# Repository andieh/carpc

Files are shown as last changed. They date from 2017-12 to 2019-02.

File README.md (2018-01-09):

# carpc
Digitalization of an old VW T3 Bulli

My old VW bulli needs some fancy power control. Mainly control of lights inside the van, disconnecting 5V power supply, theft control and so on. As an Add-on, my van has a "new" engine. The subaru EJ22 is also a boxer engine, but with way more power. And as this engine has some sort of diagnostics (pre-ODB2) included, it would be nice to visualize those informations as well.

so this project consists mainly of 3 parts:
- An Arduino (only for the easy for programming, code is plain C) (work in progress)
- A Raspberry Pi with Touchscreen and CarPC Kodi Interface (work in progress)
- ESP8266 IoT Chip for Wireless control of the functionality (t.b.d)

## Atmega328
This is the main part of the projects. Located in the back, this device will be always on. controlled by a 3x2 button interface, it enables the LED stripes in the back, starts the heater, turn on or off the 5V supply and so on. A horn is connected for alarm purposes. It checks the door state, or if the car was locked or not. 

## Raspberry Pi
Mainly for music, but also displays diagnostics from the engine, shows a navigation plugin or shows a rear cam. i currently implemented 3 plugins:
- GPIO service (enable rear cam, power enable, etc).
- Rear cam display: shows an overlay for the connected camera (usb analog s-video grabber and v4l2 / mplayer)
- Display of the EJ22 data (finished, but connection missing)

### Used Components
- Raspberry PI v.3
- Optocoupler ltv847 for detecting 12V / 5V voltages
- Servo for open and closing the display lid 
- Switch for detecting the state of the display lid
- electromagnet for holding the display lid
- Levelshifter TE291 for USART communication between Arduino / Raspbi
- IRLB8721 N-Channel Mosfets for LED stripes (controlled by the arduino)
- IRF9Z P-Channel (and BS107 Transistor) switch the 12V rail for the rear cam
- DHT 22 / AM2302 Temperature sensor 

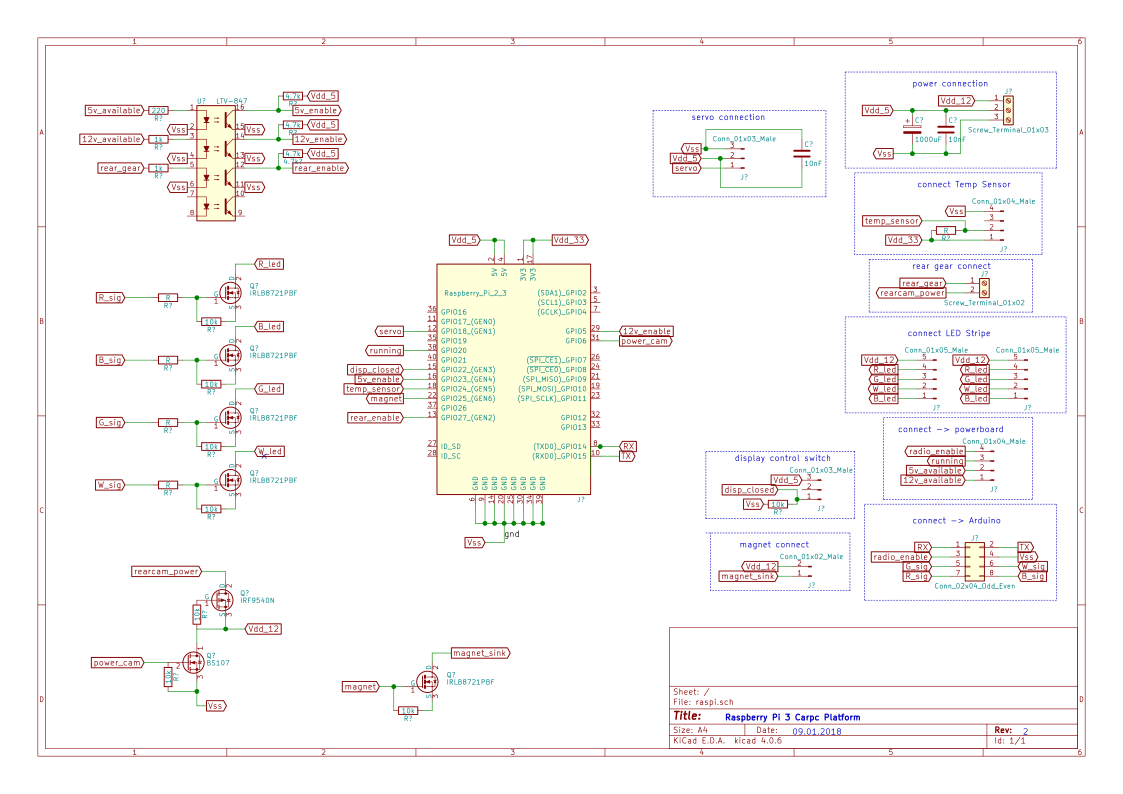
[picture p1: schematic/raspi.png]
rasp_schem


### Power supply
First try was with a 18650 Battery pack, but the Raspi, including 7'' touch
screen and GPS / Stick / S-Video consumes a lot of power (about 2-3 Amps max), 
i decided to build some analog voodoo, since there is a very big battery
already included in my (every) car. There are several ways to enable the 12V
supply: 
- button on the Arduino
- the arduino itself (with a GPIO, so power is guaranteed as long it is running)
- over the ignition
If all requests were removed, a big cap (220u) is still providing power for
some time (>10s) for the N-PMOS gate to ensure the Raspi has enough time to
shutdown. There are 3 MP1584 Buck Converter (step down) modules, which power the 
raspberry itself, one for the display and one for the USB hub. 

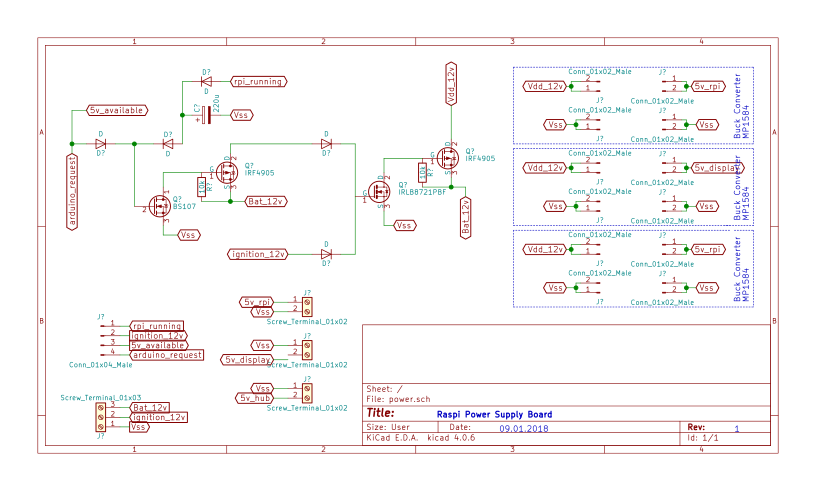
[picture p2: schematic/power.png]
power_schem


## ESP8266
Nice small thing to play with. Is directly connected to the EJ22 engine and sends data via broadcast. but currently not work in progress. to be implemented later.

Schematics (created with kicad) will be updated on time, details and more to come soon.

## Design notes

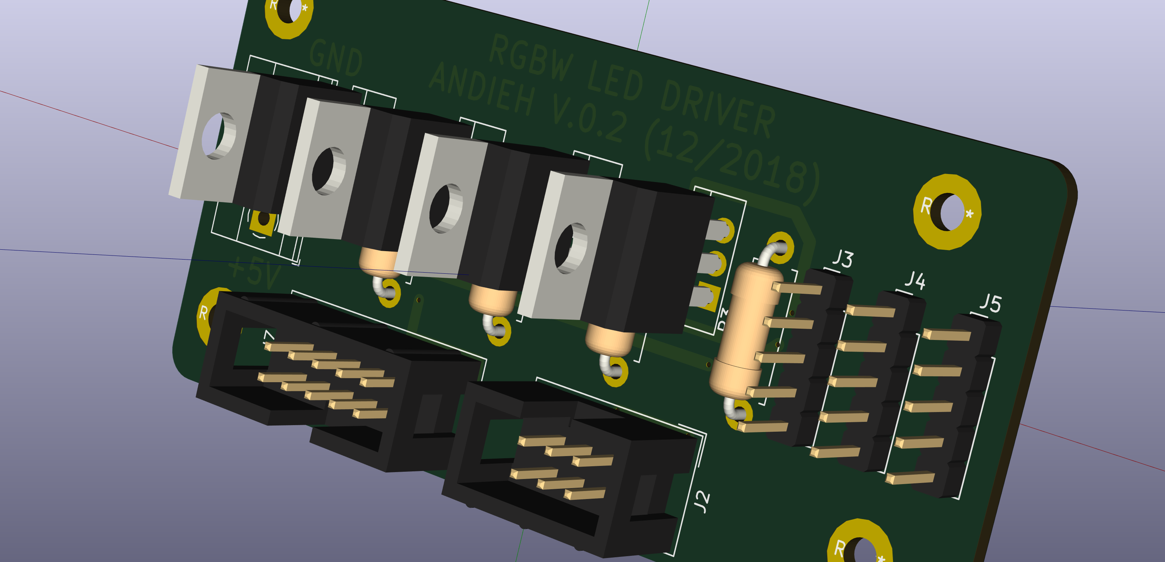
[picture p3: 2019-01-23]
schematic/led-control/led_control.png

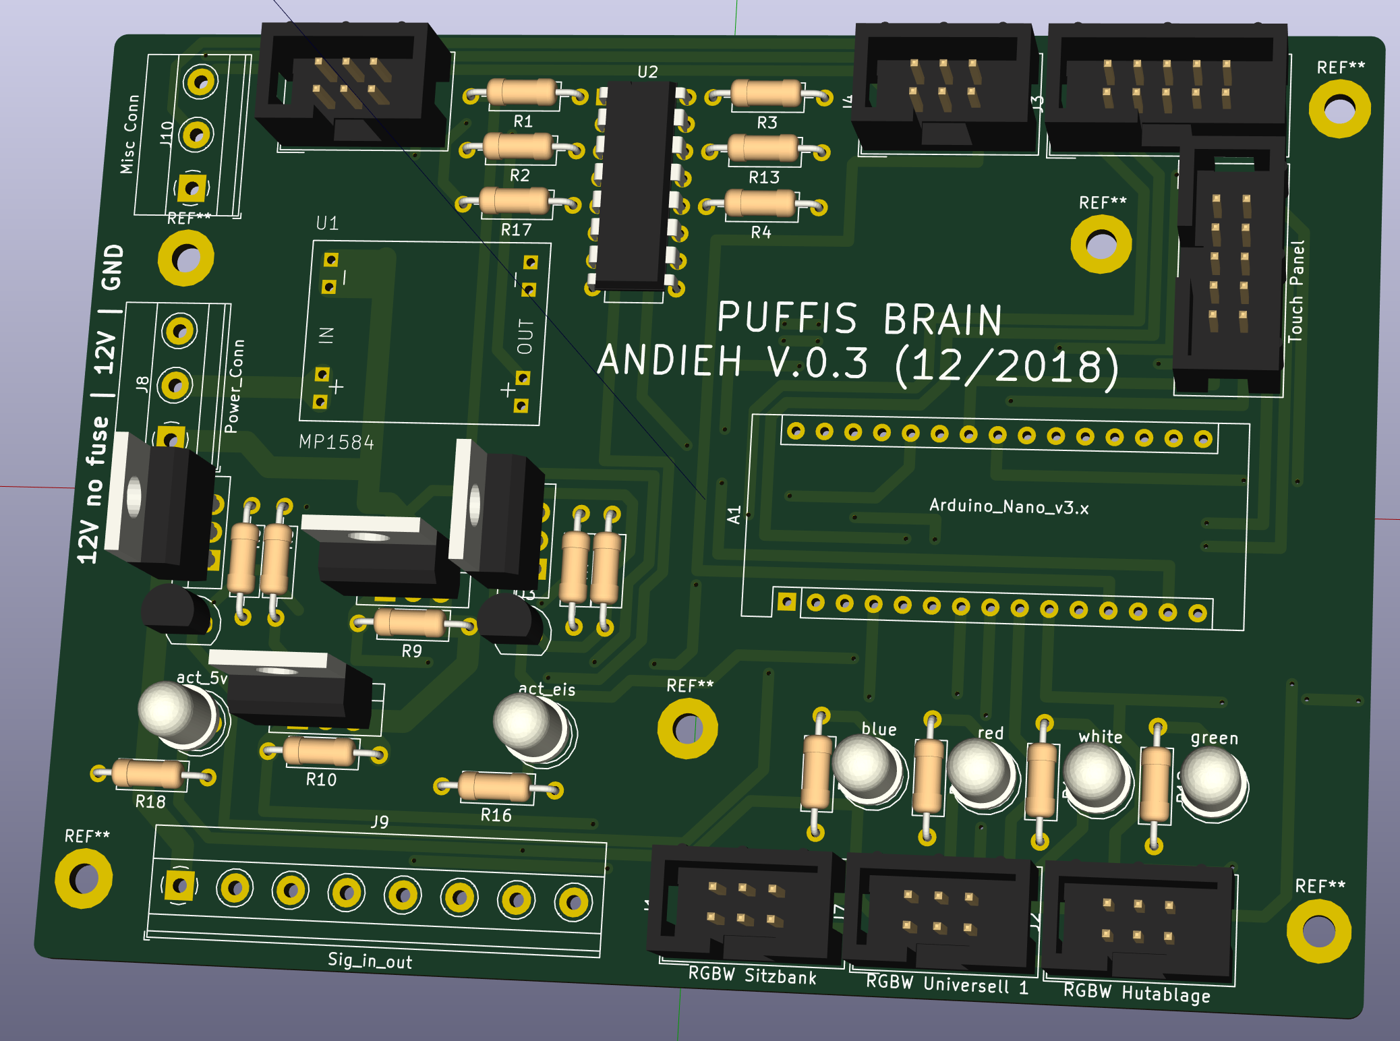
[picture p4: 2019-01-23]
schematic/car-control/car-control.png

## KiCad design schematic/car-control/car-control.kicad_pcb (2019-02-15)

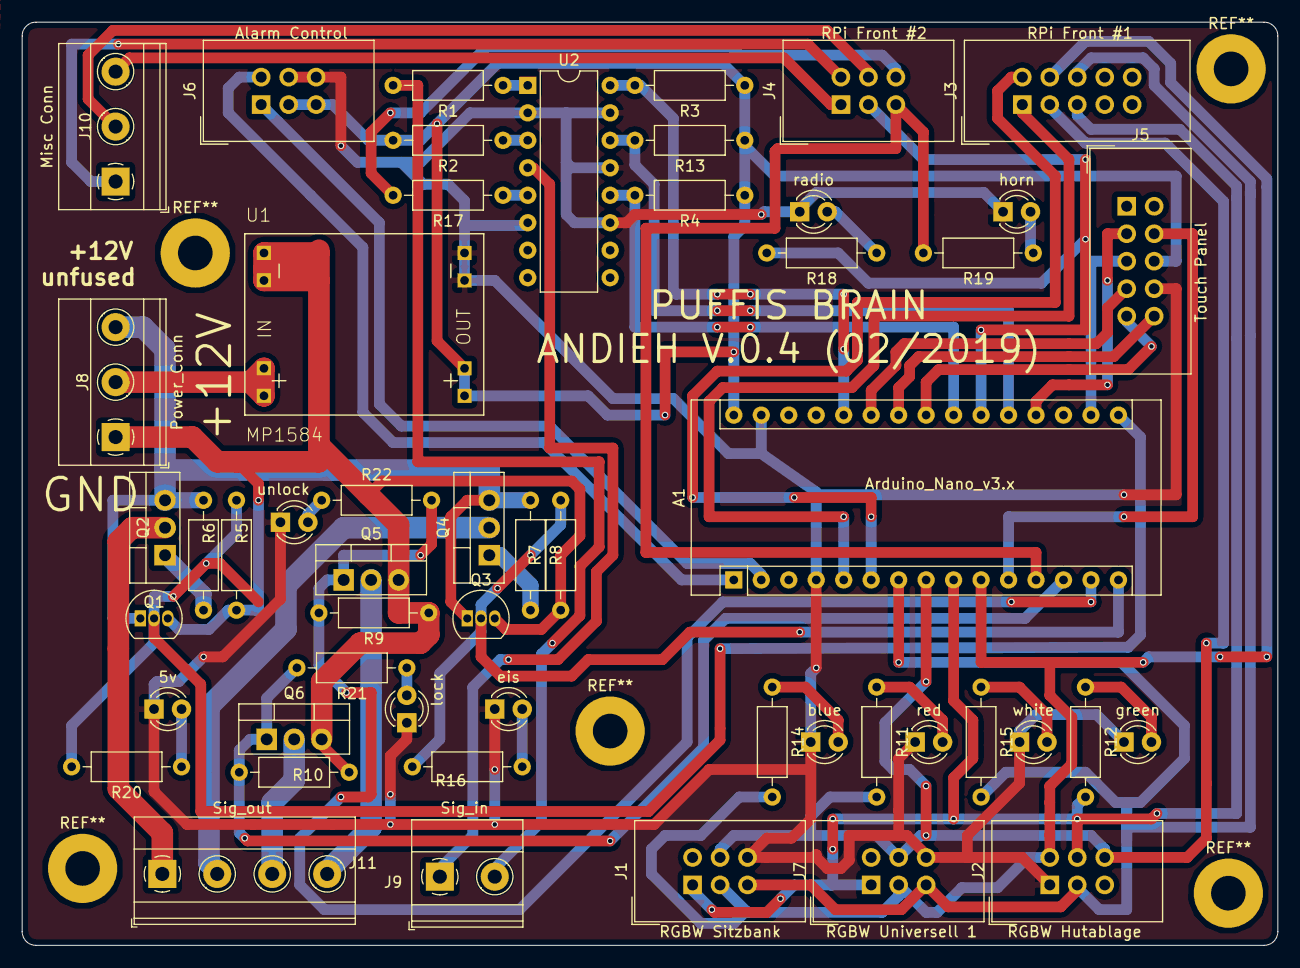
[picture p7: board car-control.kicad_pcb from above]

Board: 2 copper layers, 116.1 x 85.3 mm, 52 parts (0 on the bottom side), 53 nets.

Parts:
5v: act_5v; LED_D3.0mm_Clear
A1: Arduino_Nano_v3.x; Arduino_Nano
J1: RGBW Sitzbank; IDC-Header_2x03_P2.54mm_Vertical
J2: RGBW Hutablage; IDC-Header_2x03_P2.54mm_Vertical
J3: RPi Front #1; IDC-Header_2x05_P2.54mm_Vertical
J4: RPi Front #2; IDC-Header_2x03_P2.54mm_Vertical
J5: Touch Panel; IDC-Header_2x05_P2.54mm_Vertical
J6: Alarm Control; IDC-Header_2x03_P2.54mm_Vertical
J7: RGBW Universell 1; IDC-Header_2x03_P2.54mm_Vertical
J8: Power_Conn; TerminalBlock_Phoenix_MKDS-1,5-3-5.08_1x03_P5.08mm_Horizont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
J9: Sig_in; TerminalBlock_Phoenix_MKDS-1,5-2-5.08_1x02_P5.08mm_Horizont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
J10: Misc Conn; TerminalBlock_Phoenix_MKDS-1,5-3-5.08_1x03_P5.08mm_Horizont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
J11: Sig_out; TerminalBlock_Phoenix_MKDS-1,5-4-5.08_1x04_P5.08mm_Horizont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
Q1, Q3: BS107; TO-92_Inline
Q2, Q4: IRF9540N; TO-220-3_Vertical
Q5, Q6: IRLB8721PBF; TO-220-3_Vertical
R1, R2, R11, R12, R15, R16, R18, R19, R20, R21, R22: 220; R_Axial_DIN0207_L6.3mm_D2.5mm_P10.16mm_Horizontal
R3, R4, R13: 4.7k; R_Axial_DIN0207_L6.3mm_D2.5mm_P10.16mm_Horizontal
R5, R6, R7, R8, R9, R10: 10k; R_Axial_DIN0207_L6.3mm_D2.5mm_P10.16mm_Horizontal
R14: 120; R_Axial_DIN0207_L6.3mm_D2.5mm_P10.16mm_Horizontal
R17: 680; R_Axial_DIN0207_L6.3mm_D2.5mm_P10.16mm_Horizontal
U1: MP1584; SG053-SZ
U2: LTV-847; DIP-16_W7.62mm
blue: blue; LED_D3.0mm_Clear
eis: act_eis; LED_D3.0mm_Clear
green: green; LED_D3.0mm_Clear
horn: horn; LED_D3.0mm_Clear
lock: lock; LED_D3.0mm_Clear
radio: radio; LED_D3.0mm_Clear
red: red; LED_D3.0mm_Clear
unlock: unlock; LED_D3.0mm_Clear
white: white; LED_D3.0mm_Clear

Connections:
/220_avail: J9.2, R1.2
/220_led: A1.19, J5.3
/GND: 5v.1, A1.4, A1.29, J1.6, J2.1, J5.8, J6.4, J6.6, J7.6, U1.5, U1.6, U2.2, U2.6, U2.11, U2.13, U2.15, blue.1, eis.1, green.1, horn.1, lock.1, radio.1, red.1, unlock.1, white.1
/RX: A1.2, J6.1
/SCL: A1.23, J5.9
/SDA: A1.24, J5.10
/TX: A1.1, J6.2
/VDD: A1.30, J5.6, J6.3, J6.5, R2.2, R3.1, R4.1, R13.1, U1.7, U1.8
/analog_light: A1.25, J5.7
/cam_1_g: J4.1, J10.3
/cam_2_r: J4.2, J10.1
/cam_3_s: J4.4, J10.2
/door_gnd: J9.1, U2.4
/inp_12v: J8.2, U1.3, U1.4
/inp_12v_unfused: J8.3, Q1.1, Q2.3, Q3.1, Q4.3, R6.1, R8.1
/inp_gnd: J8.1, Q1.3, Q3.3, Q5.3, Q6.3, R5.1, R7.1, R9.1, R10.1, U1.1, U1.2
/lock_car: J11.3, Q6.2
/power_5v: J11.1, Q2.2
/power_eis: J11.2, Q4.2
/pwm_touch: A1.11, J5.4
/sig_5v: A1.16, Q1.2, R5.2, R20.2
/sig_220v: A1.26, R3.2, U2.16
/sig_b: A1.10, J1.3, J2.2, J3.4, J7.3, R14.2
/sig_door: A1.20, R13.2, U2.14
/sig_eis: A1.15, Q3.2, R7.2, R16.2
/sig_g: A1.9, J1.1, J2.4, J3.5, J7.1, R12.2
/sig_horn: A1.12, J4.5, R19.2
/sig_lock: A1.13, Q6.1, R10.2, R21.2
/sig_lock_inp: J4.6, R17.2
/sig_locked: A1.22, R4.2, U2.12
/sig_r: A1.8, J1.4, J2.6, J3.3, J7.4, R11.2
/sig_radio: A1.21, J4.3, R18.2
/sig_unlock: A1.14, Q5.1, R9.2, R22.2
/sig_w: A1.7, J1.5, J2.3, J3.6, J7.5, R15.2
/soft_RX: A1.5, J3.1
/soft_TX: A1.6, J3.2
/unlock_car: J11.4, Q5.2
/v33: A1.17, J5.5
unnamed: R11.1, red.2
unnamed: R12.1, green.2
unnamed: R14.1, blue.2
unnamed: R15.1, white.2
unnamed: R16.1, eis.2
unnamed: R19.1, horn.2
unnamed: R18.1, radio.2
unnamed: 5v.2, R20.1
unnamed: R21.1, lock.2
unnamed: R22.1, unlock.2
unnamed: Q2.1, R6.2
unnamed: Q4.1, R8.2
unnamed: R1.1, U2.1
unnamed: R2.1, U2.3
unnamed: R17.1, U2.5

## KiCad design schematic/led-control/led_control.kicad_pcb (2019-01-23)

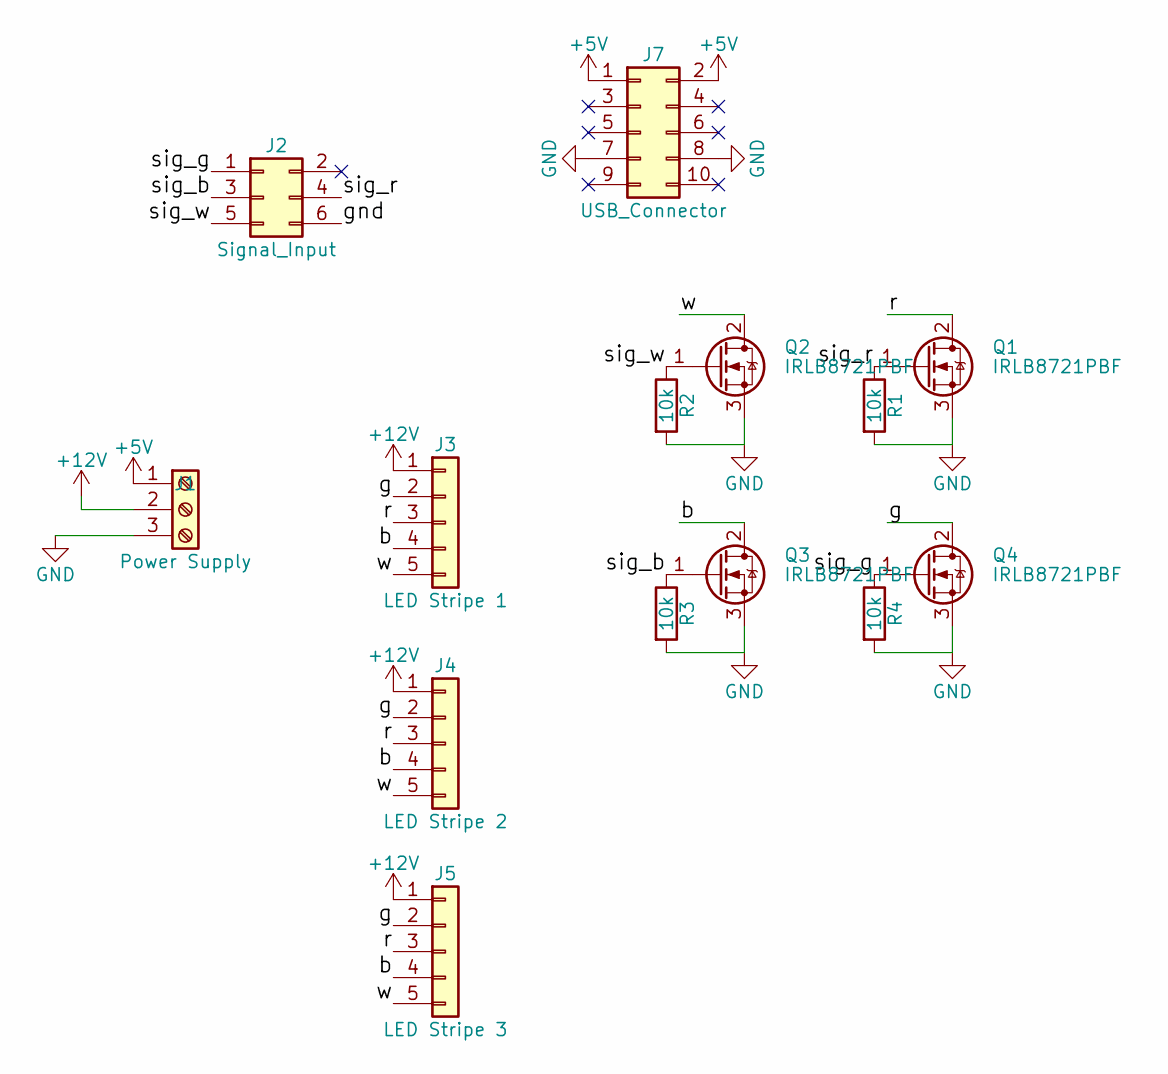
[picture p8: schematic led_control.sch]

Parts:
J1: Power Supply; TerminalBlock_Phoenix_MKDS-1,5-3-5.08_1x03_P5.08mm_Horizont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
J2: Signal_Input; IDC-Header_2x03_P2.54mm_Vertical
J3: LED Stripe 1; PinHeader_1x05_P2.54mm_Vertical
J4: LED Stripe 2; PinHeader_1x05_P2.54mm_Vertical
J5: LED Stripe 3; PinHeader_1x05_P2.54mm_Vertical
J7: USB_Connector; IDC-Header_2x05_P2.54mm_Vertical
Q1, Q2, Q3, Q4: IRLB8721PBF; TO-220-3_Vertical
R1, R2, R3, R4: 10k; R_Axial_DIN0411_L9.9mm_D3.6mm_P12.70mm_Horizontal

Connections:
+5V: J1.1, J7.1, J7.2
+12V: J1.2, J3.1, J4.1, J5.1
/b: J3.4, J4.4, J5.4, Q3.2 (D)
/g: J3.2, J4.2, J5.2, Q4.2 (D)
/r: J3.3, J4.3, J5.3, Q1.2 (D)
/sig_b: J2.3, Q3.1 (G), R3.1
/sig_g: J2.1, Q4.1 (G), R4.1
/sig_r: J2.4, Q1.1 (G), R1.1
/sig_w: J2.5, Q2.1 (G), R2.1
/w: J3.5, J4.5, J5.5, Q2.2 (D)
GND: J1.3, J2.6, J7.7, J7.8, Q1.3 (S), Q2.3 (S), Q3.3 (S), Q4.3 (S), R1.2, R2.2, R3.2, R4.2

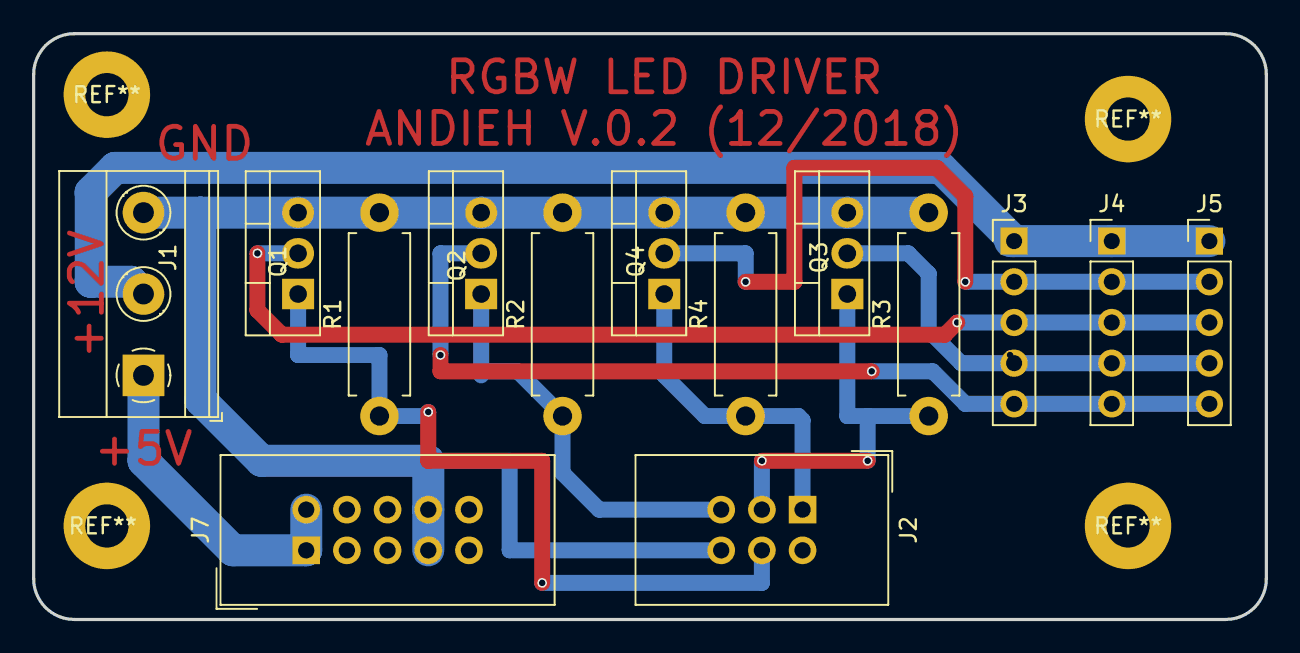
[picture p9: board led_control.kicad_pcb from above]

Board: 2 copper layers, 77.0 x 36.6 mm, 14 parts (0 on the bottom side), 11 nets.

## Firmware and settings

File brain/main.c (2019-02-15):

/**************************
 * PUFFIS BRAIN, Car-Control v.0.2
 *
 * PORTB
 * PB0  D8   >  touch_pwm   Dims the LEDs on the Touch board 
 * PB1  D9   >  sig_horn    For alarm purpurses, enable horn. 
 *                          \Todo: own board for power control?
 * PB2  D10  >  sig_lock    Locks the car using a N-Transistor
 * PB3  D11  >  NEW: sig_unlock
 *                   replaced sig_220v    check if 220V are available. 5V is read
 *                          by the optocoppler
 * PB4  D12  >  sig_eis     Enables the 12V P-Transistor output for 
 *                          the EisEx.
 * PB5  D13  >  sig_5v      Enables 12V for the 5V rail.
 *
 * PORTC
 * PC0  A0   >  NEW: 220_led
 *                   replaced analog_light  measure voltage for dimming touch LEDs
 * PC1  A1   <  sig_door      doors were opened (ground enabled)
 * PC2  A2   >  sig_radio     enabled radio in the front
 * PC3  A3   <  sig_locked    high if car is locked
 * PC4  A4   >  NEW: SCL      
 *                   replaced 220_led       indicates 220V are available 
 * PC5  A5   >  NEW: SCA      
 *                   replaced SCL i2c for touch panel
 * PC6  A6   <  NEW: analog_light   
 *                   replaced SDA i2c for touch panel
 * PC7  A7   <  NEW: sig_220v
 *                   replaced sig_unlock    Unlocks the car using a N-Transistor
 *
 * PORTD
 * PD0  RX   <  RX          Receive Data from the Arduino
 * PD1  TX   >  TX          Trasmit Data to the Alarm Arduino
 * PD2  D2   <  soft_RX     Receive Data from the RPI 
 *                          \Todo: implement this!
 * PD3  D3   >  soft TX     Transmit Data to the RPI 
 *                          \Todo: implement this!
 * PD4  D4   >  sig_w       LED Stripe, white LED
 * PD5  D5   >  sig_r       LED Stripe, red LED
 * PD6  D6   >  sig_g       LED Stripe, green LED
 * PD7  D7   >  sig_b       LED Stripe, blue LED
 *
 */

#include <avr/io.h>
#include <avr/pgmspace.h>
#include <avr/interrupt.h>
#include "types.h"
#include "defs.h"
#include <util/delay.h>
#include "i2c.h"
#include "mpr121.h"
#include "stdbool.h"
#define FOSC 8000000
#define MPR121_R 0xB5	// ADD pin is grounded
#define MPR121_W 0xB4	// So address is 0x5A

#define sbi(var, mask)   ((var) |= (uint8_t)(1 << mask))
#define cbi(var, mask)   ((var) &= (uint8_t)~(1 << mask))

#define F_PWM 100                       // PWM-Frequenz in Hz
#define PWM_STEPS 256                   // PWM-Schritte pro Zyklus(1..256)
#define PWM_DDR DDRD                    // Datenrichtungsregister für PWM

// ab hier nichts ändern, wird alles berechnet
#define T_PWM (F_CPU/(F_PWM*PWM_STEPS)) // Systemtakte pro PWM-Takt
#if (T_PWM<(93+5))
    #error T_PWM zu klein, F_CPU muss vergrössert werden oder F_PWM oder PWM_STEPS verkleinert werden
#endif

#define LED_COLOR_WHITE 0
#define LED_COLOR_BLUE 1
#define LED_COLOR_RED 2
#define LED_COLOR_GREEN 3
#define LED_COLOR_TOUCH 4

#define LED_PORT_TOUCH  PORTB
#define LED_PIN_TOUCH   PORTB0
#define LED_PORT_WHITE  PORTD
#define LED_PIN_WHITE   PORTD4
#define LED_PORT_RED    PORTD
#define LED_PIN_RED     PORTD5
#define LED_PORT_GREEN  PORTD
#define LED_PIN_GREEN   PORTD6
#define LED_PORT_BLUE   PORTD
#define LED_PIN_BLUE    PORTD7

#define IN_PORT_DOOR    PORTC
#define IN_PIN_DOOR     PC1
#define IN_PORT_LOCKED  PORTC 
#define IN_PIN_LOCKED   PC3
#define MAX_LOCK_CNT    100

#define IN_LIGHT_SENSE 6 // PC6
#define IN_220_SENSE 7 // PC7
#define LIGHT_THRESH	512

#define OUT_RADIO_PORT   PORTC
#define OUT_RADIO_PIN    PORTC2
#define OUT_EIS_PORT     PORTB
#define OUT_EIS_PIN      PORTB4
#define OUT_5V_PORT      PORTB
#define OUT_5V_PIN       PORTB5
#define OUT_220_PORT     PORTC 
#define OUT_220_PIN      PORTC0
#define OUT_LOCK_PORT    PORTB 
#define OUT_LOCK_PIN     PORTB2
#define OUT_UNLOCK_PORT  PORTB 
#define OUT_UNLOCK_PIN   PORTB3

// includes

#include <stdint.h>
#include <string.h>
#include <avr/io.h>
#include <avr/interrupt.h>
#include "uart.h"
#define UART_BAUD_RATE 9600
#define BAUDRATE 9600
#define BAUD_PRESCALLER (((F_CPU / (BAUDRATE * 16UL))) - 1)

///============Function Prototypes=========/////////////////
char mpr121Read(unsigned char address);
void mpr121Write(unsigned char address, unsigned char data);
void mpr121QuickConfig(void);
void mpr121ViewRegisters(void);
int checkInterrupt(void);
uint8_t set_new_led_color();
void set_output(volatile uint8_t *port, uint8_t pin, bool value);
ISR (TIMER2_COMPA_vect);
void USART_init(void);
unsigned char USART_receive(void);
void USART_send( unsigned char data);
void USART_putstring(char* StringPtr);
uint16_t adc_read(uint8_t adcx);

volatile uint8_t led_color[5];                    // Einstellungen für die einzelnen PWM-Kanäle
int old_led_value = 0;

int TOUCH_RADIO  = 1 << 2;
int TOUCH_EIS    = 1 << 3;
int TOUCH_LIGHT  = 1 << 4;
int TOUCH_5V     = 1 << 5;
int TOUCH_MISC   = 1 << 6;
int TOUCH_LOCK   = 1 << 7;

int LED_EIS    = 1 << 2;
int LED_LOCK   = 1 << 3;
int LED_LIGHT  = 1 << 4;
int LED_5V     = 1 << 5;
int LED_MISC   = 1 << 6;
int LED_RADIO  = 1 << 7;

bool touched_radio = false;
bool touched_eis = false;
bool touched_light = false;
bool touched_5v = false;
bool touched_misc = false;
bool touched_lock = false;

int main(void)
{
  /* Enable the ADC */
  ADCSRA |= ((1<<ADPS2)|(1<<ADPS1)|(1<<ADPS0));    //16Mhz/128 = 125Khz the ADC reference clock
  ADMUX  |= (1<<REFS0);                //Voltage reference from Avcc (5v)
  ADCSRA |= (1<<ADEN);                //Turn on ADC
  ADCSRA |= (1<<ADSC);
  
  unsigned int c;
  uart_init( UART_BAUD_SELECT(UART_BAUD_RATE,F_CPU) );
  uart_putc('\r');

  /* SOFTPWM STUFF*/
  OCR2A = 62;
  TCCR2A |= (1 << WGM21);
  // Set to CTC Mode
  TIMSK2 |= (1 << OCIE2A);
  //Set interrupt on compare match
  TCCR2B |= (1 << CS21);
  // set prescaler to 64 and starts PWM
  sei();
  // enable interrupts
	
  char touchstatus;
	ioinit();
	i2cInit();
	_delay_ms(100);
	checkInterrupt();
	
  mpr121QuickConfig();
	
	// Setup the GPIO pins to drive LEDs
	mpr121Write(GPIO_EN, 0xFF);	// 0x77 is GPIO enable
	mpr121Write(GPIO_DIR, 0xFF);	// 0x76 is GPIO Dir
	mpr121Write(GPIO_CTRL0, 0xFF);	// Set to LED driver
	mpr121Write(GPIO_CTRL1, 0xFF);	// GPIO Control 1
	mpr121Write(GPIO_CLEAR, 0xFF);	// GPIO Data Clear
	
	/*// Blink LEDs to begin
	for (int i = 0; i < 5; i++)
	{
		mpr121Write(GPIO_SET, 0xFF);
		_delay_ms(50);
		mpr121Write(GPIO_CLEAR, 0xFF);
		_delay_ms(50);
	}*/

  int delay=50;
  int state = 0x00;
  int old_new_state = state;
  
  mpr121Write(GPIO_CLEAR, 0xFF);	// Clear all LEDs
  int cnt = 0;
  int lock_led_cnt = 0;
  int touch_cnt = 0;
  int step = 0;
  uint8_t white_fade = 0;


  bool red_on = false;
  // alarm state
  enum alarm_fsm {
    ALARM_OFF = 0, // alarm is turned off 
    ALARM_WAIT,    // wait until alarm is turned on 
    ALARM_FOCUS,   // alarm is wait until released
    ALARM_DELAY,   // wait to shutdown alarm 
    ALARM          // alarm is triggered
  };
  enum alarm_fsm alarm = ALARM_OFF;  // current fsm 
  bool alarm_state = false; // alarm is active, flash lights
  int alarm_cnt = 0; // cnt for alarm
  bool alarm_triggered = false; // alarm over UART was triggered!
  bool alarm_requested = false; // alarm was requested over UART

  bool door_open = false;
  bool sig_220_out = false;
  bool sig_220_in = false;
  bool sig_in_locked = false;
  const int wait_delay= 100;

  
  /*unsigned char c = 0;*/
  bool uart_com = false;
  bool arg = false;
  uint8_t bus_argc = 0;
  int uart_command = 0;
  int uart_arg = 0;

  bool sig_5v = false;
  bool sig_eis = false;
  bool sig_radio = false;

  // lock stuff 
  int lock_cnt = 1;
  int lock_action = 0; // do nothing

  /* enable pull ups */
  IN_PORT_DOOR &= ~( 1 << IN_PIN_DOOR );
  IN_PORT_LOCKED &= ~( 1 << IN_PIN_LOCKED );

  //DDRD = DDRD | 0b11111000; //PORTD (RX on PD0), IRQ on PD2
	while(1)
	{

    ++cnt;

    if (cnt%500==0) {
      set_new_led_color();
    }

    // check if any of the doors are open
    if (!bit_is_set(PINC, IN_PIN_DOOR)) {
      door_open = true;
    } else {
      door_open = false;
    }

    // check if any of the doors are open
    if (!bit_is_set(PINC, IN_PIN_LOCKED)) {
      sig_in_locked = true;
    } else {
      sig_in_locked = false;
    }

    // check if 220V are available
    uint16_t analog_val_220 = adc_read(IN_220_SENSE);
    if (analog_val_220 < 200) {
      sig_220_in = true;
    } else {
      sig_220_in = false;
    }

    // read cap touch via i2c
		touchstatus = mpr121Read(0x00);	// Read touch status
		touchstatus = touchstatus << 2;	// Shift two bits over
    if (touch_cnt > 0)
      --touch_cnt;
    
    ++step;
    ++alarm_cnt;
    ++lock_cnt;
    
    if (step > 100000) 
      step = 0;
    
    bool touch_change = false;
    if (touch_cnt == 0) {
      for (int i = 2; i < 8; ++i) {
        if (touchstatus & (1<<i)) {
          touch_cnt = wait_delay;
          touch_change = true;
          if (state & (1<<i))
            state &= ~(1<<i);
          else 
            state |= (1<<i);
        }
      }
    }
    
    if (touch_change) {
      //enables light
      if (state & TOUCH_LIGHT) touched_light = true;
      else touched_light = false;
      if (state & TOUCH_EIS) touched_eis = true;
      else touched_eis = false;
      if (state & TOUCH_5V) touched_5v = true;
      else touched_5v = false;
      if (state & TOUCH_MISC) touched_misc = true;
      else touched_misc = false;
      if (state & TOUCH_LOCK) touched_lock = true;
      else touched_lock = false;
      if (state & TOUCH_RADIO) touched_radio = true;
      else touched_radio = false;
    }
 
    if (touched_5v) {
      sig_5v = true;
    } else {
      sig_5v = false;
    }

    if (touched_eis) {
      sig_eis = true;
    } else {
      sig_eis = false;
    }

    if (touched_radio) {
      sig_radio = true;
    } else {
      sig_radio = false;
    }

    if (touched_lock) {
      // we want to lock or unlock the car. 
      // this is based on the state of the car.
      if (sig_in_locked) // car is locked, so we want to unlock it
        lock_action = 1;
      else 
        lock_action = 2;
      lock_cnt = 0;
      state &= ~(TOUCH_LOCK);
      touched_lock = false;
    }

    sig_220_out = sig_220_in;

    c = uart_getc();
    if (!(c&UART_NO_DATA)) {
      //uart_putc( (unsigned char)c );
      if (c == 60) { // start communication with '<'
        uart_com = true;
        arg = false;
        uart_command = 0;
        uart_arg = 0;
  
      } else if (!uart_com) {
        // foo
      
      } else if (c == 62) { // stop communication with '>'
        uart_com = false;
        // run my commands!
        if (uart_command == 48) { // 0
          if (uart_arg == 48) { // off 
            alarm_requested = false; 
            alarm = ALARM_OFF;
            state &= ~(1<<3);
            red_on = false;
          } else if (uart_arg == 49) { // on     
            alarm_requested = true;
            alarm_cnt = 0;
          }
        
        } else if (uart_command == 49) { // 0
          if (uart_arg == 49) { // alarm triggered
            alarm_triggered = true;
          } else if (uart_arg == 48) {
            alarm_triggered = false;
          }
        }

      } else {
        if (!arg) {
          uart_command = c;
          arg = true;
        } else {
          uart_arg = c;
        }
      }

    }



    if (alarm != ALARM) {
      if (door_open || touched_light) {
        if (white_fade < 128) {
          ++white_fade;
          _delay_ms(5);
        }
        led_color[LED_COLOR_WHITE] = white_fade;
      } else if (white_fade > 0) {
        --white_fade;
        _delay_ms(5);
        led_color[LED_COLOR_WHITE] = white_fade;
      } else {
        white_fade = 0;
        led_color[LED_COLOR_WHITE] = 0;
      }
    }
  
    // request alarm over UART
    if (alarm_requested) {
      red_on = true;
    }

    if (alarm == ALARM_OFF) {
      alarm_triggered = false;
      led_color[LED_COLOR_RED] = 0;
      if (red_on) {
        alarm = ALARM_WAIT;
        alarm_cnt = 0;
      }
    } else if (alarm == ALARM_WAIT) {
      if (!red_on) 
        alarm = ALARM_OFF;
      if (alarm_cnt > 2*128 && alarm_cnt < 4*128) {
        led_color[LED_COLOR_RED] = 0;
      } else if (alarm_cnt > 5*128) {
        alarm = ALARM_FOCUS;
        //USART_putstring("<0|1>");
        led_color[LED_COLOR_RED] = 0;
      } else {
        led_color[LED_COLOR_RED] = 2*(alarm_cnt % 128);
      }
    } else if (alarm == ALARM_FOCUS) {
      if (door_open || alarm_triggered) {
        alarm_cnt = 0;
        alarm = ALARM;
      }
      if (!red_on) {
        alarm = ALARM_OFF;
        //USART_putstring("<0|0>");
      }
    } else if (ALARM == alarm) {
      if (!red_on) {
        alarm = ALARM_OFF;
        //USART_putstring("<0|0>");
      }
      if (!alarm_triggered && !door_open && (alarm_cnt > 1000)) {
        alarm = ALARM_FOCUS;
        alarm_state = false;
        alarm_cnt = 1;
        led_color[LED_COLOR_RED] = 0;
      }
      led_color[LED_COLOR_WHITE] = 0;
      if (alarm_cnt % 100 == 0)
        alarm_state = !alarm_state;
      if (alarm_state)
        led_color[LED_COLOR_RED] = 128;
      else 
        led_color[LED_COLOR_RED] = 0;
    }

    set_output(&OUT_5V_PORT, OUT_5V_PIN, sig_5v);
    set_output(&OUT_EIS_PORT, OUT_EIS_PIN, sig_eis);
    set_output(&OUT_RADIO_PORT, OUT_RADIO_PIN, sig_radio);
    set_output(&OUT_220_PORT, OUT_220_PIN, sig_220_out);

    if (lock_cnt == 0) {
      if (lock_action == 1)
        set_output(&OUT_UNLOCK_PORT, OUT_UNLOCK_PIN, 1);
      else if (lock_action == 2)
        set_output(&OUT_LOCK_PORT, OUT_LOCK_PIN, 1);

    } else if (lock_cnt == MAX_LOCK_CNT) { 
      set_output(&OUT_LOCK_PORT, OUT_LOCK_PIN, 0);
      set_output(&OUT_UNLOCK_PORT, OUT_UNLOCK_PIN, 0);
    } else if (lock_cnt > MAX_LOCK_CNT) {
      lock_cnt = 1;
    }

    led_color[LED_COLOR_GREEN] = 0;
    led_color[LED_COLOR_BLUE] = 0;
    //led_color[LED_COLOR_RED] = 0;

    // calculate new LED state 
    int new_state = 0x00; //state;
    // if light was requested or doors are opened, 
    // toggle button
    if (door_open || touched_light)
      new_state |= (LED_LIGHT);

    if (touched_radio) 
      new_state |= (LED_RADIO);

    if (touched_5v) 
      new_state |= (LED_5V);

    if (touched_eis)
      new_state |= (LED_EIS);

    if (touched_misc)
      new_state |= (LED_MISC);

    // if the car is locked, we want to blink the button
    bool glow_lock_led = false;
    if (sig_in_locked) {
      ++lock_led_cnt;
      if (lock_led_cnt < 50) 
        glow_lock_led = true;
      else if (lock_led_cnt < 700)
        glow_lock_led = false;
      else 
        lock_led_cnt = 0;
    } else {
      lock_led_cnt = 0;
    }

    if (glow_lock_led)
      new_state |= (LED_LOCK);
    
    if (new_state != old_new_state) {
      mpr121Write(GPIO_CLEAR, 0xFF);	// Clear all LEDs
      mpr121Write(GPIO_SET, new_state);	// Set LED 
      old_new_state = new_state;
    }

	} // end loop
}




/*
 * ALL THOSE functions
 */
uint16_t adc_read(uint8_t adcx) {
  ADMUX &= 0xF0;                    //Clear the older channel that was read
  ADMUX |= adcx;                //Defines the new ADC channel to be read
  ADCSRA |= (1<<ADSC);                //Starts a new conversion
  while(ADCSRA & (1<<ADSC));            //Wait until the conversion is done
  return ADCW;  
}

ISR (TIMER2_COMPA_vect) {
    static uint8_t pwm_cnt=0;
    OCR1A += (uint16_t)T_PWM;
        
    //set_output(&LED_PORT_WHITE, LED_PIN_WHITE, (led_color[LED_COLOR_WHITE] > pwm_cnt));
    if (led_color[LED_COLOR_WHITE] > pwm_cnt)
      LED_PORT_WHITE |= (_BV(LED_PIN_WHITE));
    else
      LED_PORT_WHITE &= ~(_BV(LED_PIN_WHITE));

    //set_output(&LED_PORT_BLUE, LED_PIN_BLUE, (led_color[LED_COLOR_BLUE] > pwm_cnt));
    if (led_color[LED_COLOR_BLUE] > pwm_cnt)
      LED_PORT_BLUE |= (_BV(LED_PIN_BLUE));
    else
      LED_PORT_BLUE &= ~(_BV(LED_PIN_BLUE));
    
    //set_output(&LED_PORT_RED, LED_PIN_RED, (led_color[LED_COLOR_RED] > pwm_cnt));
    if (led_color[LED_COLOR_RED] > pwm_cnt)
      LED_PORT_RED |= (_BV(LED_PIN_RED));
    else
      LED_PORT_RED &= ~(_BV(LED_PIN_RED));
    
    //set_output(&LED_PORT_GREEN, LED_PIN_GREEN, (led_color[LED_COLOR_GREEN] > pwm_cnt));
    if (led_color[LED_COLOR_GREEN] > pwm_cnt)
      LED_PORT_GREEN |= (_BV(LED_PIN_GREEN));
    else
      LED_PORT_GREEN &= ~(_BV(LED_PIN_GREEN));
    
    //set_output(&LED_PORT_TOUCH, LED_PIN_TOUCH, (led_color[LED_COLOR_TOUCH] > pwm_cnt));
    if (led_color[LED_COLOR_TOUCH] > pwm_cnt)
      LED_PORT_TOUCH |= (_BV(LED_PIN_TOUCH));
    else
      LED_PORT_TOUCH &= ~(_BV(LED_PIN_TOUCH));

    //PWM_PORT = tmp;                         // PWMs aktualisieren
    if (pwm_cnt==(uint8_t)(PWM_STEPS-1))
        pwm_cnt=0;
    else
        pwm_cnt++;
}

uint8_t set_new_led_color() {
  uint16_t val = adc_read(IN_LIGHT_SENSE); // / 4;     // read the input pin 

#if 0
  USART_putstring("raw value: ");
  char str[16];
  itoa(val, str, 10);
  USART_putstring(str);
  USART_putstring("\n");
#endif 

  int t = val - 130;
  float rat = t / 500.;
  float full = rat * 255.f;
  uint8_t ret = 0;

  if (full < 10.) 
    ret = 10;
  else if (full > 255.)
    ret = 255;
  else 
    ret = (uint8_t)full;
 
#if 0
  USART_putstring("set to value: ");
  char str2[16];
  itoa(ret, str2, 10);
  USART_putstring(str2);
  USART_putstring("\n");
#endif 
  led_color[LED_COLOR_TOUCH] = ret;
}

void set_output(volatile uint8_t *port, uint8_t pin, bool value) {
  if (value)
    *port |= (_BV(pin));
  else
    *port &= ~(_BV(pin));
}
void USART_init(void){
 UBRR0H = (uint8_t)(BAUD_PRESCALLER>>8);
 UBRR0L = (uint8_t)(BAUD_PRESCALLER);
 UCSR0B = (1<<RXEN0)|(1<<TXEN0);
 UCSR0C = (3<<UCSZ00);
}
 
unsigned char USART_receive(void){
 while(!(UCSR0A & (1<<RXC0)));
 return UDR0;
}
 
void USART_send( unsigned char data){
 while(!(UCSR0A & (1<<UDRE0)));
 UDR0 = data;
}
 
void USART_putstring(char* StringPtr){
while(*StringPtr != 0x00){
 USART_send(*StringPtr);
 StringPtr++;}
}

char mpr121Read(unsigned char address)
{
	char data;
	
	i2cSendStart();
	i2cWaitForComplete();
	
	i2cSendByte(MPR121_W);	// write 0xB4
	i2cWaitForComplete();
	
	i2cSendByte(address);	// write register address
	i2cWaitForComplete();
	
	i2cSendStart();
	
	i2cSendByte(MPR121_R);	// write 0xB5
	i2cWaitForComplete();
	i2cReceiveByte(TRUE);
	i2cWaitForComplete();
	
	data = i2cGetReceivedByte();	// Get MSB result
	i2cWaitForComplete();
	i2cSendStop();
	
	cbi(TWCR, TWEN);	// Disable TWI
	sbi(TWCR, TWEN);	// Enable TWI
	
	return data;
}

void mpr121Write(unsigned char address, unsigned char data)
{
	i2cSendStart();
	i2cWaitForComplete();
	
	i2cSendByte(MPR121_W);	// write 0xB4
	i2cWaitForComplete();
	
	i2cSendByte(address);	// write register address
	i2cWaitForComplete();
	
	i2cSendByte(data);
	i2cWaitForComplete();
	
	i2cSendStop();
}

// MPR121 Quick Config
// This will configure all registers as described in AN3944
// Input: none
// Output: none
void mpr121QuickConfig(void)
{
	// Section A
	// This group controls filtering when data is > baseline.
	mpr121Write(MHD_R, 0x01);
	mpr121Write(NHD_R, 0x01);
	mpr121Write(NCL_R, 0x00);
	mpr121Write(FDL_R, 0x00);
	
	// Section B
	// This group controls filtering when data is < baseline.
	mpr121Write(MHD_F, 0x01);
	mpr121Write(NHD_F, 0x01);
	mpr121Write(NCL_F, 0xFF);
	mpr121Write(FDL_F, 0x02);
	
	// Section C
	// This group sets touch and release thresholds for each electrode
	mpr121Write(ELE0_T, TOU_THRESH);
	mpr121Write(ELE0_R, REL_THRESH);
	mpr121Write(ELE1_T, TOU_THRESH);
	mpr121Write(ELE1_R, REL_THRESH);
	mpr121Write(ELE2_T, TOU_THRESH);
	mpr121Write(ELE2_R, REL_THRESH);
	mpr121Write(ELE3_T, TOU_THRESH);
	mpr121Write(ELE3_R, REL_THRESH);
	mpr121Write(ELE4_T, TOU_THRESH);
	mpr121Write(ELE4_R, REL_THRESH);
	mpr121Write(ELE5_T, TOU_THRESH);
	mpr121Write(ELE5_R, REL_THRESH);
	
	// Section D
	// Set the Filter Configuration
	// Set ESI2
	mpr121Write(FIL_CFG, 0x04);
  
  // 0xC0 = 11 0xFF
  // 0x40 = 01 0x7F
  // 0x80 = 10 0xBF
  // 0x00 = 00 0x3F
  mpr121Write(0x5C, 0xFF);
	
	// Section E
	// Electrode Configuration
	// Enable 6 Electrodes and set to run mode
	// Set ELE_CFG to 0x00 to return to standby mode
	// mpr121Write(ELE_CFG, 0x0C);	// Enables all 12 Electrodes
	mpr121Write(ELE_CFG, 0x06);		// Enable first 6 electrodes
	
	// Section F
	// Enable Auto Config and auto Reconfig
	/*mpr121Write(ATO_CFG0, 0x0B);
	mpr121Write(ATO_CFGU, 0xC9);	// USL = (Vdd-0.7)/vdd*256 = 0xC9 @3.3V
	mpr121Write(ATO_CFGL, 0x82);	// LSL = 0.65*USL = 0x82 @3.3V
	mpr121Write(ATO_CFGT, 0xB5);*/	// Target = 0.9*USL = 0xB5 @3.3V
}

int checkInterrupt(void)
{
	if ((PIND & (1<<2)) == 0)
		return 0;
	else
		return 1;
}

/*********************
 ****Initialize****
 *********************/
 
void ioinit (void)
{
    //1 = output, 0 = input
	DDRB = 0b00111111; //PORTB4, B5 output
  DDRC = 0b00110001; //PORTC4 (SDA), PORTC5 (SCL), PORTC all others are inputs
  DDRD = 0b11111010; //PORTD (RX on PD0), IRQ on PD2
	
  PORTC = 0b00110000; //pullups on the I2C bus
  
  //DDRC = 0b00010011; //PORTC4 (SDA), PORTC5 (SCL), PORTC all others are inputs
}

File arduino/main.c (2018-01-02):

/*
 *
 *               ----------------------------------
 *               |           ARDUINO UNO          |
 *               |            --------            |
 *               |            |      | PC5     A4 |
 *               |            |      | PC4     A5 |
 *               |            |      |       AREF |
 *               |            |      |        GND |
 *               |            |      | PB5    D13 | < QH (buttons) 
 *               | NC         |ATMEGA| PB4    D12 | > CLK (buttons)
 *               | IOREF      | 328P | PB3    D11 | > G channel (PWM)
 *               | 3V3        |      | PB2    D10 | > Horn, Alarm
 *               | 5V         |      | PB1     D9 | > R channel (PWM)
 *               | GND        |      | PB0     D8 | > SHLD (buttons)
 *               | GND        |      |            |
 *               | Vin        |      | PD7     D7 | > 12V radio enable (front)
 *               |            |      | PD6     D6 | > CLK (LED shift register)
 *               | A0     PC0 |      | PD5     D5 | > Data (LEDs shift register)
 *   220V avail  | A1     PC1 |      | PD4     D4 | > TX (softuart RPi)
 *   door open > | A2     PC2 |      | PD3     D3 | > B channel (PWM)
 *   white LED < | A3     PC3 |      | PD2     D2 | < RX (softuart RPi)
 *  car locked > | A4     PC4 |      | PD1     D1 | > TX (EJ22)
 *      5V out < | A5     PC5 |      | PD0     D0 | < RX (EJ22)
 *               |            --------            |
 *               |---------------------------------
 *
 *  t.b.d.:
 *  - input: doors open?
 *  - ESP8622: - connection to the ESP8622??? RX / TX 
 *             - enable / disable?
 *
 *
 * BUTTONS:
 *  ----------------------------------------------
 *  |              |              |              |
 *  |   inlight    |    alarm     |     dim+     |
 *  |              |              |              |
 *  ----------------------------------------------
 *  |              |              |              |
 *  |  5V enable   |    radio     |     dim-     |
 *  |              |              |              |
 *  |              |              |              |
 *  ----------------------------------------------
 *
 */


#include <avr/interrupt.h>
#include <avr/pgmspace.h>
#include "softuart.h"
#include <util/delay.h>
#include <stdbool.h>
#include "led.h"
#include "buttons.h"

#include <stdlib.h>
#include <avr/io.h>
#include <stdio.h>
#include <stdint.h>
#include <avr/sfr_defs.h>

// read of LEDs 
// 2 pins for setting up to unlimited number 
// of LEDs. in our case up to 8 (two shift 
// registers).
// PD5 = digital 5
// PD6 = digital 6
#define CP_PIN  PORTD5 // clock
#define CP_PORT PORTD
#define DP_PIN  PORTD6 // data
#define DP_PORT PORTD 
// definition of the position of led to set
#define LED_RADIO  0 // enable radio
#define LED_WHITE  1 // enable light inside
#define LED_ELSE2  2 // 5 volt rail enabled?
#define LED_ALARM  3 // enable / disable alarm
#define LED_ELSE1  4 // t.b.d.
#define LED_FIVE   5 // t.b.d.
#define LED_POWER  6 // shows a 220V connection
#define LED_LOCKED   7 // display locked car
 
// button connection definition
// 3 pins for reading up to 8 buttons
// PB0 = digital 8
// PB4 = digital 12 (miso)
// PB5 = digital 13 (SCK) 
#define SHLD      PORTB0 
#define CLK       PORTB4 
#define QH        PORTB5 
#define DDR_SHLD  DDRB
#define PORT_SHLD PORTB
#define DDR_CLK   DDRB
#define PORT_CLK  PORTB
#define DDR_QH    DDRB
#define PORT_QH   PORTB
#define PIN_QH    PINB /* This is the only input. */

// inputs 
#define DOOR_OPEN_PORT   PORTC
#define DOOR_OPEN_PIN    PORTC2
#define DOOR_LOCKED_PORT PORTC
#define DOOR_LOCKED_PIN  PORTC4
#define AC_AVAIL_PORT    PORTC
#define AC_AVAIL_PIN     PORTC1

// outputs 
#define RADIO_OUT_PORT   PORTD
#define RADIO_OUT_PIN    PORTD7
#define ALARM_OUT_PORT   PORTB
#define ALARM_OUT_PIN    PORTB2
#define FIVE_OUT_PORT    PORTC
#define FIVE_OUT_PIN     PORTC5

char *ftoa(char *buffer, double d, int precision) {

	long wholePart = (long) d;

	// Deposit the whole part of the number.

	itoa(wholePart,buffer,10);

	// Now work on the faction if we need one.

	if (precision > 0) {

		// We do, so locate the end of the string and insert
		// a decimal point.

		char *endOfString = buffer;
		while (*endOfString != '\0') endOfString++;
		*endOfString++ = '.';

		// Now work on the fraction, be sure to turn any negative
		// values positive.

		if (d < 0) {
			d *= -1;
			wholePart *= -1;
		}
		
		double fraction = d - wholePart;
		while (precision > 0) {

			// Multipleby ten and pull out the digit.

			fraction *= 10;
			wholePart = (long) fraction;
			*endOfString++ = '0' + wholePart;

			// Update the fraction and move on to the
			// next digit.

			fraction -= wholePart;
			precision--;
		}

		// Terminate the string.

		*endOfString = '\0';
	}

   return buffer;
}

void init_buttons(void) {
    /* In input mode, when pull-up is enabled, default state of pin becomes ’1′. So even if */
    /* you don’t connect anything to pin and if you try to read it, it will read as 1. Now, */
    /* when you externally drive that pin to zero(i.e. connect to ground / or pull-down),   */
    /* only then it will be read as 0. */
    /* Enable pullups by setting bits in PORT. Default state is now high. */
    DDR_SHLD |= (_BV(SHLD));  /* Output */
    DDR_CLK |= (_BV(CLK));  /* Output */
    DDR_QH &= ~(_BV(QH)); /* Input  */
}

uint8_t digital_read(int input_register, int pin) {
    return bit_is_set(input_register, pin) != 0 ? 1 : 0;
}

/* You could use cbi ie &= ~ or sbi ie |= but this makes code more readable. */
void digital_write(volatile uint8_t *data_port, uint8_t pin, uint8_t value) {
    if (0 == value) {
        *data_port &= ~(_BV(pin));
    } else {
        *data_port |= _BV(pin);
    }
}

void set_leds(uint8_t leds) {
  uint8_t MAX_LEDS = 8; // number of LEDs connected
  for (uint8_t i = MAX_LEDS; i > 0; --i) {
    if (bit_is_set(leds,(i-1)))
      DP_PORT |= (_BV(DP_PIN));
    else
      DP_PORT &= ~(_BV(DP_PIN));
    CP_PORT |= (_BV(CP_PIN));
    CP_PORT &= ~(_BV(CP_PIN));
  }
}

uint8_t set_led(uint8_t leds, bool cond, uint8_t pin) {
  if (cond) 
    leds |= ( 1 << pin);
  else 
    leds &= ~(1 << pin);
  return leds;
}

float myFloat = 1.23456;
char myFloatStr[8];
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

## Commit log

2017-11-17 working with UART and PWM
2017-11-27 dimming, and button are working
2017-11-28 new button stuff
2017-12-13 combined actual state with led and button registers
2017-12-16 arduino and pi working over softuart
2017-12-22 add new system scripts, new power circuit
2017-12-23 jeah, rear camera working
2017-12-25 white LED working, some cleanup
2017-12-31 more with white LED
2017-12-31 set rgb color over uart, fix power dialog
    [main.c, serialTest.py, service.py]
2018-01-07 motor control added on boot up
2018-01-09 add first schematic view for raspberry pi layout
    [arduino.kicad_pcb, arduino.sch, raspi.kicad_pcb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]
2018-01-09 added power schematic
    [power.kicad_pcb, power.sch]
2018-01-09 minor in power schematic
    [power.sch]
2019-01-14 ok, lets go again
    [arduino.kicad_pcb, arduino.sch, power.sch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]
2019-01-17 more in LED stuff, connection in/outputs mostly working
2019-01-23 added more schematics
    [car-alarm-B.Cu.gbl, car-alarm-B.Mask.gbs, car-alarm-B.SilkS.gbo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]
2019-02-15 i really have no glue what i have done since the last checkin
    [car-control.kicad_pcb, car-control.sch]
